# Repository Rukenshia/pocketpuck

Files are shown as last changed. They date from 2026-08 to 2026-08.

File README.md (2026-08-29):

# PocketPuck

> [!NOTE]
> This project is not associated with Amp. It's just a fun little side project to put Puck on my desk.

| | |
| --- | --- |
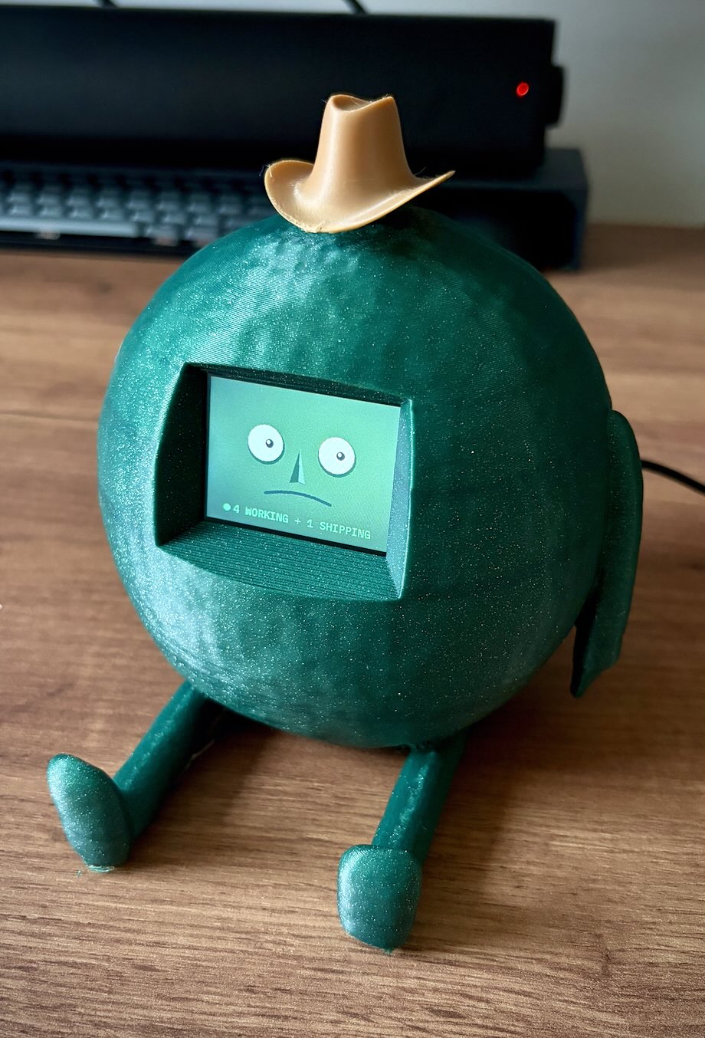
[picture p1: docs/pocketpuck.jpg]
An image of the PocketPuck device
|  | A body for Puck, [Amp](https://ampcode.com)'s companion. Synchronises your current thread state and lets you know if you need to take action. It's also very cute. |

Full video demo:

<video controls src="https://github.com/user-attachments/assets/eebd0190-7875-4f72-867d-91fb097cefb3"></video>

## Usage

Once connected, PocketPuck will automatically synchronise with your current Amp thread state. It will let you know if you have any threads waiting for you or tell you that there are new messages waiting for you (= a thread probably finished).

You press the dial once to open a thread overview that allows you to scroll through your threads. Pressing the dial again will then show a little bit more information on that thread. Long press the dial to get back to the main screen.

To open the Settings, long press the dial from the main screen. You can change the display fae, change whether Puck should blink or not, and reset all settings. Settings are persisted. There are a total of four display faces to choose from: from a very minimal one to reduce distractions to what you can see in the video (and even more unhinged).

## Hardware

- Arduino Nano ESP32 (any ESP32 will work, but you might have to change pinout assignments)
- [Waveshare 2inch LCD Module](https://www.waveshare.com/wiki/2inch_LCD_Module)
  (240 x 320, ST7789V)
- Rotary encoder with push button (KY-040 or similar)

### 3D Models

You can find the 3d models in the `models` directory. You have a choice of multiple hats to give your PocketPuck some extra personality.

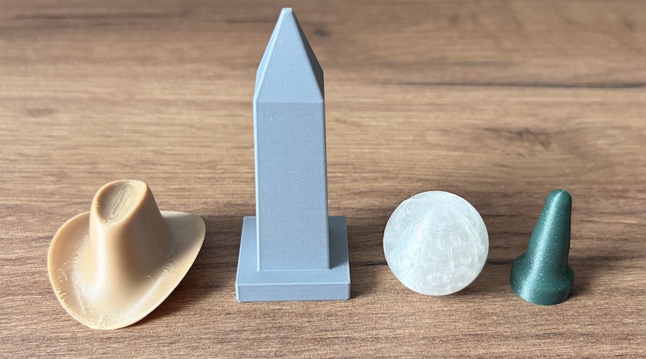
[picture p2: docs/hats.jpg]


| Model Name | Description |
| --- | --- |
| `puck_manual.stl`  | The main body of the PocketPuck. |
| `puck_hat.stl` | A cute cowboy hat. |
| `puck_obelisk.stl` | A small obelisk to put on top of the PocketPuck. |
| `puck_orb.stl` | An orb as a hat. Recommended to print with a translucent filament |
| `puck_knob.stl` | An interestingly shaped knob as a hat. |

You can hot glue the display to the inside of the body or use tape to secure it. The rotary dial goes through the hole and is fastened with a nut.

### Wiring

Disconnect USB power while wiring. The table below refers to the Arduino Nano ESP32 pin labels, not the normal ESP32 GPIO pinout.

| Waveshare LCD | Nano ESP32 | Purpose |
| --- | --- | --- |
| `VCC` | `3V3` | Power |
| `GND` | `GND` | Ground |
| `DIN` | `D11` / `COPI` | SPI data to display |
| `CLK` | `D12` / `CIPO` | Remapped SPI clock |
| `CS` | `D10` | Chip select |
| `DC` | `D7` | Data/command select |
| `RST` | `D8` | Display reset |
| `BL` | `D9` | Backlight, active high |

| Rotary encoder | Nano ESP32 | Purpose |
| --- | --- | --- |
| `CLK` | `D2` | Rotation clock |
| `DT` | `D3` | Rotation direction |
| `SW` | `D4` | Push switch |
| `+` | `D5` | Module pull-up voltage (you should connect this to 3V3 but I was lazy) |
| `GND` | `GND` | Common ground |

### Build and upload

[PlatformIO](https://platformio.org/) is the only required development tool.

```sh
pio run
pio run --target upload
pio device monitor
```

PlatformIO should automatically find the Nano ESP32's USB port. If an upload
cannot find the board, double-press RESET to enter the Arduino bootloader (the
green LED pulses), then run the upload command again.

The display and rotary pin assignments live in
[`include/display_config.h`](include/display_config.h).
The firmware uses the Adafruit GFX and ST7789 libraries, fetched automatically
by PlatformIO.

## Live Amp stats

Amp's API does not support all the thread information that I wanted to display.
PocketPuck therefor uses Rivet endpoint directly to get more detailed information,
meaning this can break at any time since there is no published API contract for this.
The bridge has a fallback to the `amp top` command, which is more stable but less detailed.

The bridge should be deployed on in the same network as PocketPuck. The server
serves traffic over HTTP on port 8765 by default. It is written in [Bun](https://bun.sh/).

I personally run this on a Raspberry Pi, where I also run Amp, meaning that I can use my
existing credentials. You can provide a custom API key using the `AMP_API_KEY` environment variable.

```sh
$HOME/.bun/bin/bun install --frozen-lockfile --production --ignore-scripts
```

Start the bridge service and query it with:

```sh
$HOME/.bun/bin/bun scripts/pocketpuck_bridge.mjs \
  --amp-command "$HOME/.amp/bin/amp"
curl http://localhost:8765/stats
```

By default, the bridge will try to find credentials in

- `$HOME/.config/amp/secrets.json`
- `$XDG_CONFIG_HOME/amp/secrets.json`
- `$HOME/.local/share/amp/secrets.json`

To run the bridge as a systemd user service, use a unit like this (adjust the
repository path if the checkout is not `%h/pocketpuck`):

```ini
[Unit]
Description=PocketPuck Amp bridge
After=network-online.target

[Service]
WorkingDirectory=%h/pocketpuck
ExecStart=%h/.bun/bin/bun scripts/pocketpuck_bridge.mjs --amp-command %h/.amp/bin/amp
# Optional custom-deployment overrides; normal Amp file credentials are discovered.
EnvironmentFile=-%h/.config/pocketpuck/environment
Restart=always

[Install]
WantedBy=default.target
```

## Connecting Your PocketPuck to the Bridge

Copy the example network configuration file to a local file that you can edit:

```sh
cp include/network_config.example.h include/network_config.h
```

Edit the `POCKETPUCK_WIFI_SSID`, `POCKETPUCK_WIFI_PASSWORD`, and `POCKETPUCK_STATS_URL` (for example `http://192.168.178.123:8765/stats`) values accordingly. Note that most ESP32 only support 2.4GHz WiFi networks, so make sure your router is configured correctly.

## FAQ (nobody has asked me anything yet)

> Why?

I sometimes start threads and then go on to do other things (definitely not procrastinating). I wanted a way to know if I have threads waiting for me. So instead of enabling notifications on my phone, I decided to build something completely unnecessary.

> Why is he so thick?

I overestimated how much space I needed inside and I have not modelled anything in Blender for a long time. This was supposed to just take a few days and I wanted to stick to that timeline.
The display being inset so deeply is also a result of me not having enough patience to do things properly in Blender. I've been using OnShape for most of my things recently and am just out of practice.

> Why do his hands look so weird?

It was my first time ever trying to even use the Blender sculpting tools and I regret everything.

> Why PocketPuck? He clearly does not fit into my pocket.

My original idea was much more boring (a small case around the display and a small stand), but I pivoted to something more fun. By that time, the repo already existed.

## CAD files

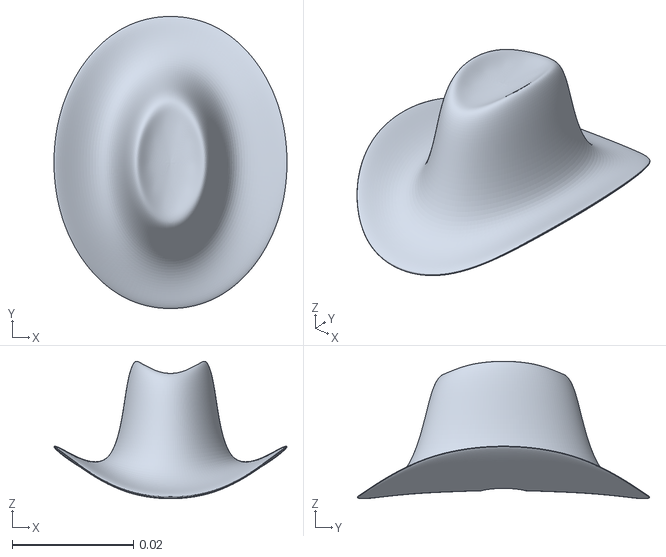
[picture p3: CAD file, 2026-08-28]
models/puck_hat.stl
0.0385 x 0.0483 x 0.0227

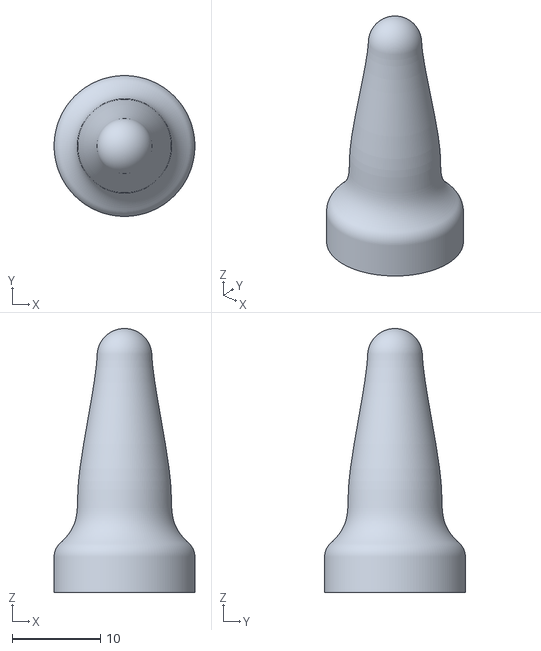
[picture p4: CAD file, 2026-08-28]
models/puck_knob.stl
16.0 x 16.0 x 30.0

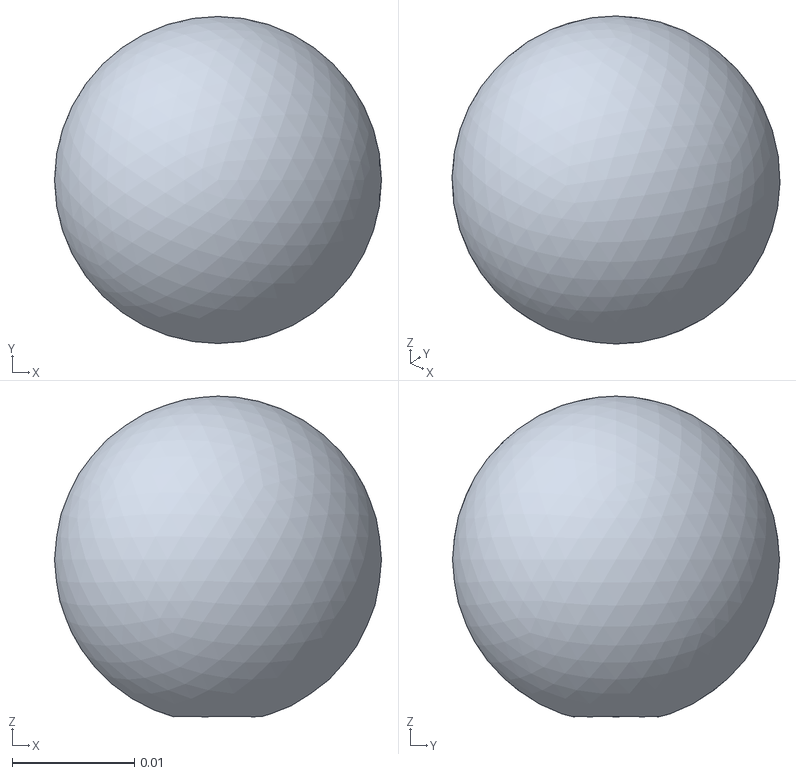
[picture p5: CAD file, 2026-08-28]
models/puck_orb.stl
0.0267 x 0.0267 x 0.0262

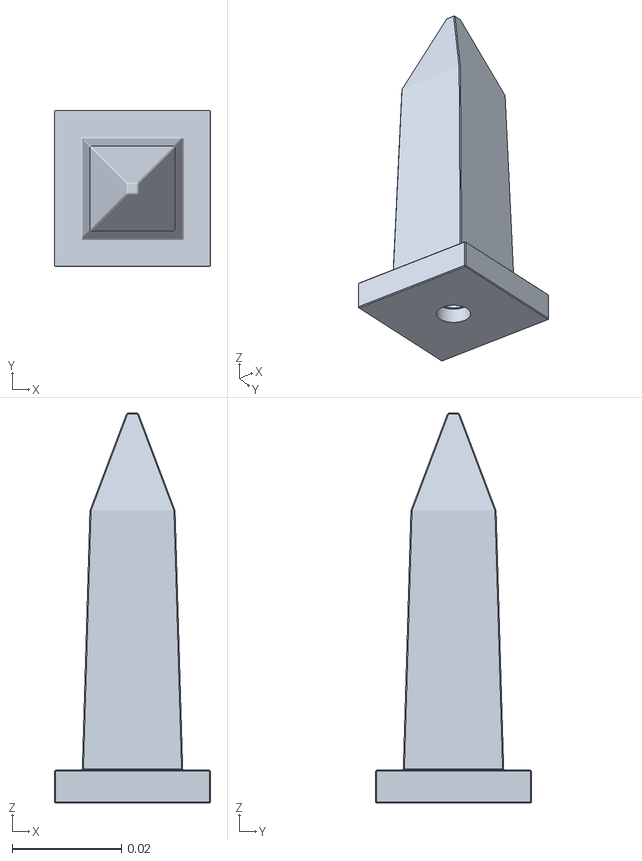
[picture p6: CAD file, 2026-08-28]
models/puck_obelisk.stl
0.0286 x 0.0286 x 0.0713

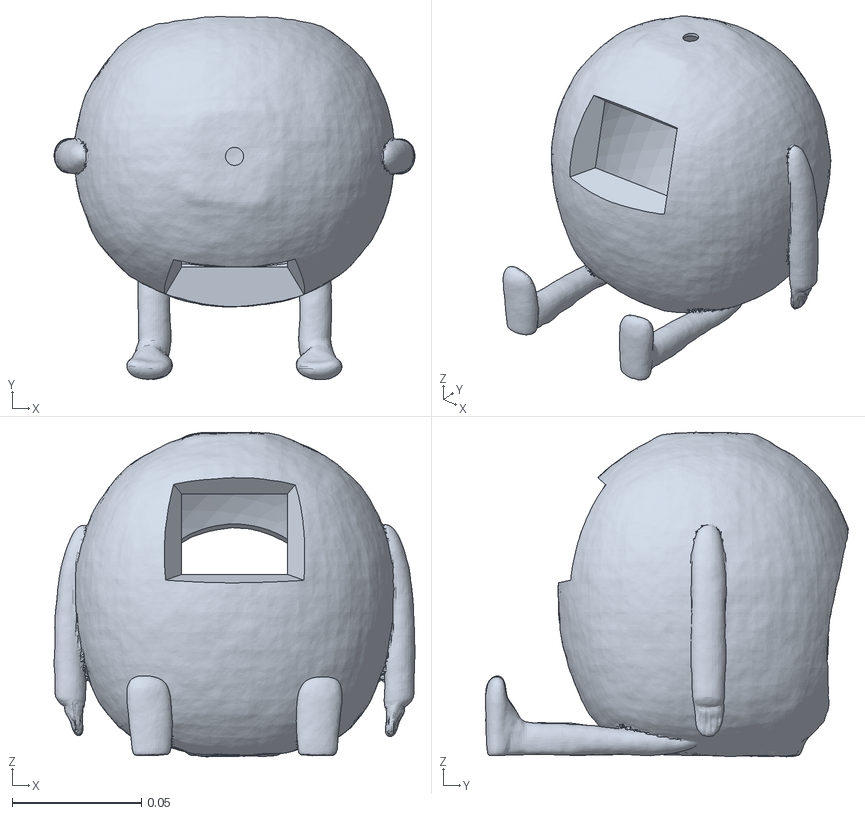
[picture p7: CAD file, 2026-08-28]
models/puck_manual.stl
0.14 x 0.14 x 0.126

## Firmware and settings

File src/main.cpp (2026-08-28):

#include <Adafruit_GFX.h>
#include <Adafruit_ST7789.h>
#include <Arduino.h>
#include <Preferences.h>
#include <SPI.h>
#include <algorithm>
#include <cmath>
#include <cstdio>
#include <cstring>

#include "amp_stats.h"
#include "amp_logo.h"
#include "display_config.h"
#include "fonts/PlexMono9pt7b.h"

// Snapshot-backed UI scenes exceed Arduino's default 8 KB loop task stack.
SET_LOOP_TASK_STACK_SIZE(16 * 1024);

namespace {

Adafruit_ST7789 display(LCD_CS, LCD_DC, LCD_RST);

constexpr int16_t SCREEN_WIDTH = 320;
constexpr int16_t SCREEN_HEIGHT = 240;
constexpr size_t SCREEN_PIXEL_COUNT = SCREEN_WIDTH * SCREEN_HEIGHT;
constexpr uint32_t FRAME_INTERVAL_MS = 80;
constexpr float IRIS_SMOOTHING_TIME_MS = 180.0F;
constexpr uint8_t DEPTH_LAYER_COUNT = 8;
constexpr float FULL_ROTATION_RADIANS = 6.283185307F;
constexpr int16_t FACE_Y_OFFSET = 12;
constexpr uint8_t BACKLIGHT_MIN = 31;
constexpr uint8_t BACKLIGHT_STEP = 32;
constexpr uint32_t BUTTON_DEBOUNCE_MS = 30;
constexpr uint32_t ENCODER_FEEDBACK_MS = 1500;
constexpr uint32_t LONG_PRESS_MS = 700;
constexpr uint32_t MENU_TIMEOUT_MS = 30000;
constexpr uint32_t NOTIFICATION_DURATION_MS = 4200;
constexpr uint32_t SHIPPED_NOTIFICATION_DURATION_MS =
    NOTIFICATION_DURATION_MS + 5000;
constexpr uint8_t NOTIFICATION_QUEUE_LIMIT = 8;
constexpr uint8_t SEEN_EVENT_LIMIT = AMP_THREAD_EVENT_LIMIT;

constexpr uint32_t LOGO_ROTATION_MS = 5000;
constexpr uint32_t STARTUP_LOGO_DURATION_MS = 5000;
constexpr uint32_t CONNECTING_FACE_MIN_DURATION_MS = 2000;
constexpr uint32_t WAKING_ANIMATION_DURATION_MS = 2000;

// Confirmed faces render live Amp state. The picker runs the synchronized
// fixture lifecycle while the dial previews each design.
constexpr uint8_t REEL_VERSION = 6;
constexpr uint8_t REEL_MODE_COUNT = 3;
constexpr uint8_t DEFAULT_REEL_MODE = 1;
constexpr uint8_t DEBUG_FACE_PHASE_COUNT = 5;
constexpr uint32_t REEL_OVERLAY_MS = 1800;
constexpr uint32_t IDLE_MESSAGE_DELAY_MS = 20 * 60 * 1000;
constexpr uint32_t IDLE_MESSAGE_INTERVAL_MS = 20 * 60 * 1000;
constexpr uint32_t IDLE_MESSAGE_DURATION_MS = 2 * 60 * 1000;
const char* const REEL_MODE_NAMES[REEL_MODE_COUNT] = {
    "MINIMAL", "BEACON", "PANIC",
};
const char* const DEBUG_FACE_PHASE_NAMES[DEBUG_FACE_PHASE_COUNT] = {
    "IDLE", "WORKING", "MESSAGE", "ATTENTION", "ALL CLEAR",
};
const char* const IDLE_MESSAGES[] = {
    "Quiet here.",
    "Still here.",
    "Suspiciously quiet.",
    "Nothing has exploded.",
    "I await developments.",
    "A rare moment of order.",
    "Threads asleep. Allegedly.",
    "All systems plausible.",
};

constexpr int16_t LOGO_FRAME_WIDTH = AMP_LOGO_WIDTH;
constexpr int16_t LOGO_FRAME_HEIGHT = AMP_LOGO_HEIGHT + 24;
constexpr int16_t LOGO_FRAME_ROW_BYTES = (LOGO_FRAME_WIDTH + 7) / 8;
constexpr size_t LOGO_FRAME_BYTES =
    LOGO_FRAME_ROW_BYTES * LOGO_FRAME_HEIGHT;

GFXcanvas16 canvas(SCREEN_WIDTH, SCREEN_HEIGHT);
uint8_t logoFrame[LOGO_FRAME_BYTES];
uint8_t logoHighlight[LOGO_FRAME_BYTES];
uint8_t sourceRow[AMP_LOGO_WIDTH];

uint16_t logoBackground;
uint16_t logoDepthColors[4];
uint16_t logoFaceColor;
uint16_t logoHighlightColor;
uint16_t faceShadowColor;
uint16_t eyeShadowColor;
uint16_t eyeColor;
uint16_t pupilColor;
uint16_t eyeHighlightColor;
uint16_t noseShadowColor;
uint16_t noseLightColor;
uint16_t mouthColor;
uint16_t accentColor;
uint16_t unreadColor;
uint16_t textureColor;
uint16_t threadCardColor;
uint16_t workingColor;
uint16_t shippingColor;

uint32_t demoStartedAt = 0;
uint32_t lastFrameAt = 0;
uint32_t initialSetupCompletedAt = 0;
uint32_t wifiConnectionStartedAt = 0;
uint32_t wakingAnimationStartedAt = 0;
bool ampStatsStarted = false;
bool connectingFaceDrawn = false;
uint8_t backlightBrightness = 255;
portMUX_TYPE encoderMux = portMUX_INITIALIZER_UNLOCKED;
DRAM_ATTR const int8_t encoderTransitions[16] = {
    0, -1, 1, 0, 1, 0, 0, -1, -1, 0, 0, 1, 0, 1, -1, 0,
};
volatile uint8_t encoderState = 0;
volatile int8_t encoderQuarterSteps = 0;
volatile int8_t pendingEncoderSteps = 0;
uint32_t lastEncoderStepAt = 0;
bool encoderFeedbackActive = false;
int8_t lastEncoderDirection = 0;
bool buttonReading = false;
bool buttonPressed = false;
bool buttonLongHandled = false;
uint32_t buttonChangedAt = 0;
uint32_t buttonPressedAt = 0;
uint32_t lastBrowserInteractionAt = 0;

enum class UiPage : uint8_t {
  Face,
  MainMenu,
  Settings,
  ThreadList,
  ThreadDetail,
};
enum class NotificationKind : uint8_t {
  None,
  Attention,
  Message,
  ThreadActive,
  Shipped,
};

struct PendingNotification {
  NotificationKind kind = NotificationKind::None;
  char title[AMP_THREAD_TITLE_LENGTH] = "";
  char state[AMP_THREAD_STATE_LENGTH] = "";
};

UiPage uiPage = UiPage::Face;
uint8_t mainMenuIndex = 0;
uint8_t settingsMenuIndex = 0;
bool blinkingEnabled = false;
uint32_t settingsResetAt = 0;
bool debugFaceActive = false;
uint8_t debugFacePhase = 0;
uint32_t debugFacePhaseChangedAt = 0;
uint8_t selectedThreadIndex = 0;
uint8_t firstVisibleThreadIndex = 0;
char selectedThreadId[AMP_THREAD_ID_LENGTH] = "";
char selectedThreadTitle[AMP_THREAD_TITLE_LENGTH] = "";
AmpThreadSummary detailThread;
bool detailUnreadAvailable = false;
uint8_t detailThreadTotal = 0;
NotificationKind notificationKind = NotificationKind::None;
uint32_t notificationElapsedMs = 0;
uint32_t notificationUpdatedAt = 0;
char notificationThreadTitle[AMP_THREAD_TITLE_LENGTH] = "";
char notificationThreadState[AMP_THREAD_STATE_LENGTH] = "";
PendingNotification notificationQueue[NOTIFICATION_QUEUE_LIMIT];
uint8_t notificationQueueCount = 0;
char seenEventIds[SEEN_EVENT_LIMIT][AMP_EVENT_ID_LENGTH] = {};
uint8_t seenEventCount = 0;
uint8_t nextSeenEventIndex = 0;
AmpStatsSnapshot previousStats;
bool statsBaselineReady = false;
uint32_t reelAllClearStartedAt = 0;

uint8_t reelMode = DEFAULT_REEL_MODE;
uint8_t reelModeBeforeSelection = DEFAULT_REEL_MODE;
uint32_t reelModeChangedAt = 0;
bool reelModeSelecting = false;
uint32_t reelSelectionStartedAt = 0;
uint32_t idleMessageCycleStartedAt = 0;

struct FacePose {
  float gazeX = 0.0F;
  float gazeY = 0.0F;
  float leftEyeOpen = 1.0F;
  float rightEyeOpen = 1.0F;
  float eyeScale = 1.0F;
  float pupilScale = 1.0F;
  float mouthCurveY = 150.0F;
  float mouthTilt = 0.0F;
  float xOffset = 0.0F;
  float yOffset = 0.0F;
};

float irisTargetX = 0.0F;
float irisTargetY = 0.0F;
float irisPositionX = 0.0F;
float irisPositionY = 0.0F;
uint32_t irisUpdatedAt = 0;
bool irisSmoothingReady = false;

void pushCanvas();

void IRAM_ATTR handleEncoderChange() {
  const uint8_t newState =
      (digitalRead(ROTARY_CLK) << 1) | digitalRead(ROTARY_DT);

  portENTER_CRITICAL_ISR(&encoderMux);
  encoderQuarterSteps += encoderTransitions[(encoderState << 2) | newState];
  encoderState = newState;
  if (encoderQuarterSteps >= 4) {
    if (pendingEncoderSteps < 100) {
      ++pendingEncoderSteps;
    }
    encoderQuarterSteps = 0;
  } else if (encoderQuarterSteps <= -4) {
    if (pendingEncoderSteps > -100) {
      --pendingEncoderSteps;
    }
    encoderQuarterSteps = 0;
  }
  portEXIT_CRITICAL_ISR(&encoderMux);
}

void adjustBacklight(int8_t direction) {
  const int16_t adjusted = static_cast<int16_t>(backlightBrightness) +
                           direction * BACKLIGHT_STEP;
  backlightBrightness =
      static_cast<uint8_t>(std::max<int16_t>(BACKLIGHT_MIN,
                                             std::min<int16_t>(255, adjusted)));
  analogWrite(LCD_BL, backlightBrightness);
  Serial.printf("Backlight: %u%%\n",
                (backlightBrightness * 100U + 127U) / 255U);
}

void showFace() {
  uiPage = UiPage::Face;
  debugFaceActive = false;
  reelModeSelecting = false;
  encoderFeedbackActive = false;
  Serial.println("Screen: face");
}

void showMainMenu(uint32_t now) {
  if (reelModeSelecting) {
    reelMode = reelModeBeforeSelection;
    reelModeSelecting = false;
  }
  uiPage = UiPage::MainMenu;
  debugFaceActive = false;
  mainMenuIndex = 0;
  lastBrowserInteractionAt = now;
  encoderFeedbackActive = false;
  Serial.println("Screen: main menu");
}

void showSettings(uint32_t now) {
  uiPage = UiPage::Settings;
  debugFaceActive = false;
  settingsMenuIndex = 0;
  lastBrowserInteractionAt = now;
  encoderFeedbackActive = false;
  Serial.println("Screen: settings");
}

void showFacePicker(uint32_t now) {
  uiPage = UiPage::Face;
  debugFaceActive = false;
  reelModeBeforeSelection = reelMode;
  reelModeSelecting = true;
  reelModeChangedAt = now;
  reelSelectionStartedAt = now;
  encoderFeedbackActive = false;
  Serial.println("Face picker: turn to preview, click to confirm");
}

void showDebugFace(uint32_t now) {
  uiPage = UiPage::Face;
  debugFaceActive = true;
  debugFacePhase = 0;
  debugFacePhaseChangedAt = now;
  lastBrowserInteractionAt = now;
  encoderFeedbackActive = false;
  Serial.printf("Debug face: %s; turn to change state, press to return\n",
                DEBUG_FACE_PHASE_NAMES[debugFacePhase]);
}

int16_t selectedThreadPosition(const AmpStatsSnapshot& stats) {
  for (uint8_t index = 0; index < stats.threadCount; ++index) {
    const AmpThreadSummary& thread = stats.threads[index];
    if ((selectedThreadId[0] &&
         std::strcmp(selectedThreadId, thread.id) == 0) ||
        (!selectedThreadId[0] && selectedThreadTitle[0] &&
         std::strcmp(selectedThreadTitle, thread.title) == 0)) {
      return index;
    }
  }
  return -1;
}

void rememberSelectedThread(const AmpThreadSummary& thread) {
  std::snprintf(selectedThreadId, sizeof(selectedThreadId), "%s", thread.id);
  std::snprintf(selectedThreadTitle, sizeof(selectedThreadTitle), "%s",
                thread.title);
}

void keepSelectedThreadVisible(uint8_t threadCount) {
  constexpr uint8_t visibleThreads = 4;
  if (threadCount <= visibleThreads) {
    firstVisibleThreadIndex = 0;
    return;
  }
  if (selectedThreadIndex < firstVisibleThreadIndex) {
    firstVisibleThreadIndex = selectedThreadIndex;
  } else if (selectedThreadIndex >=
             firstVisibleThreadIndex + visibleThreads) {
    firstVisibleThreadIndex = selectedThreadIndex - visibleThreads + 1;
  }
  firstVisibleThreadIndex = std::min<uint8_t>(
      firstVisibleThreadIndex, threadCount - visibleThreads);
}

bool reconcileSelectedThread(const AmpStatsSnapshot& stats) {
  if (!stats.available || stats.threadCount == 0) {
    return false;
  }
  const int16_t position = selectedThreadPosition(stats);
  if (position >= 0) {
    selectedThreadIndex = static_cast<uint8_t>(position);
  } else {
    selectedThreadIndex = std::min<uint8_t>(selectedThreadIndex,
                                            stats.threadCount - 1);
    rememberSelectedThread(stats.threads[selectedThreadIndex]);
  }
  keepSelectedThreadVisible(stats.threadCount);
  return true;
}

void showThreadList(uint32_t now) {
  const AmpStatsSnapshot stats = getAmpStats();
  reconcileSelectedThread(stats);
  uiPage = UiPage::ThreadList;
  lastBrowserInteractionAt = now;
  encoderFeedbackActive = false;
  Serial.println("Screen: thread list");
}

void openSelectedThread(uint32_t now) {
  const AmpStatsSnapshot stats = getAmpStats();
  if (!reconcileSelectedThread(stats)) {
    return;
  }
  detailThread = stats.threads[selectedThreadIndex];
  rememberSelectedThread(detailThread);
  detailUnreadAvailable = stats.unreadAvailable;
  detailThreadTotal = stats.threadCount;
  uiPage = UiPage::ThreadDetail;
  lastBrowserInteractionAt = now;
  Serial.printf("Screen: thread %u of %u\n", selectedThreadIndex + 1,
                stats.threadCount);
}

void navigateThreads(int8_t steps, uint32_t now, bool showDetail) {
  const AmpStatsSnapshot stats = getAmpStats();
  if (!reconcileSelectedThread(stats)) {
    return;
  }
  const int16_t next = static_cast<int16_t>(selectedThreadIndex) + steps;
  selectedThreadIndex = static_cast<uint8_t>(std::max<int16_t>(
      0, std::min<int16_t>(stats.threadCount - 1, next)));
  rememberSelectedThread(stats.threads[selectedThreadIndex]);
  keepSelectedThreadVisible(stats.threadCount);
  lastBrowserInteractionAt = now;
  if (showDetail) {
    detailThread = stats.threads[selectedThreadIndex];
    detailUnreadAvailable = stats.unreadAvailable;
    detailThreadTotal = stats.threadCount;
  }
}

bool refreshThreadDetail() {
  const AmpStatsSnapshot stats = getAmpStats();
  if (!stats.available) {
    return true;
  }
  const int16_t position = selectedThreadPosition(stats);
  if (position < 0) {
    return false;
  }
  selectedThreadIndex = static_cast<uint8_t>(position);
  detailThread = stats.threads[selectedThreadIndex];
  detailUnreadAvailable = stats.unreadAvailable;
  detailThreadTotal = stats.threadCount;
  return true;
}

void saveSelectedFace() {
  Preferences preferences;
  preferences.begin("pocketpuck", false);
  preferences.putUChar("design", reelMode);
  preferences.putUChar("designVer", REEL_VERSION);
  preferences.end();
}

void saveBlinkingPreference() {
  Preferences preferences;
  preferences.begin("pocketpuck", false);
  preferences.putBool("blink", blinkingEnabled);
  preferences.remove("noBlink");
  preferences.end();
}

void resetSettings(uint32_t now) {
  Preferences preferences;
  preferences.begin("pocketpuck", false);
  preferences.clear();
  preferences.end();

  reelMode = DEFAULT_REEL_MODE;
  blinkingEnabled = false;
  debugFaceActive = false;
  debugFacePhase = 0;
  debugFacePhaseChangedAt = now;
  reelModeChangedAt = now;
  settingsResetAt = now;
  Serial.println("Settings reset to defaults");
}

void handleShortPress(uint32_t now) {
  if (uiPage == UiPage::Face && debugFaceActive) {
    showSettings(now);
  } else if (uiPage == UiPage::Face && reelModeSelecting) {
    reelModeSelecting = false;
    reelModeChangedAt = now;
    saveSelectedFace();
    Serial.printf("Design confirmed: %u/%u %s\n", reelMode + 1,
                  REEL_MODE_COUNT, REEL_MODE_NAMES[reelMode]);
  } else if (uiPage == UiPage::MainMenu) {
    if (mainMenuIndex == 0) {
      showFacePicker(now);
    } else {
      showSettings(now);
    }
  } else if (uiPage == UiPage::Settings) {
    lastBrowserInteractionAt = now;
    if (settingsMenuIndex == 0) {
      blinkingEnabled = !blinkingEnabled;
      saveBlinkingPreference();
      Serial.printf("Blinking: %s\n", blinkingEnabled ? "enabled" : "disabled");
    } else if (settingsMenuIndex == 1) {
      showDebugFace(now);
    } else {
      resetSettings(now);
    }
  } else if (uiPage == UiPage::ThreadDetail) {
    showThreadList(now);
  } else if (uiPage == UiPage::ThreadList) {
    openSelectedThread(now);
  } else {
    showThreadList(now);
  }
}

void updateControls(uint32_t now) {
  portENTER_CRITICAL(&encoderMux);
  const int8_t encoderSteps = pendingEncoderSteps;
  pendingEncoderSteps = 0;
  portEXIT_CRITICAL(&encoderMux);
  if (encoderSteps != 0) {
    if (uiPage == UiPage::MainMenu) {
      const int16_t next = static_cast<int16_t>(mainMenuIndex) + encoderSteps;
      mainMenuIndex = static_cast<uint8_t>(
          std::max<int16_t>(0, std::min<int16_t>(1, next)));
      lastBrowserInteractionAt = now;
    } else if (uiPage == UiPage::Settings) {
      const int16_t next =
          static_cast<int16_t>(settingsMenuIndex) + encoderSteps;
      settingsMenuIndex = static_cast<uint8_t>(
          std::max<int16_t>(0, std::min<int16_t>(2, next)));
      lastBrowserInteractionAt = now;
    } else if (uiPage == UiPage::ThreadList) {
      navigateThreads(encoderSteps, now, false);
    } else if (uiPage == UiPage::ThreadDetail) {
      navigateThreads(encoderSteps, now, true);
    } else if (reelModeSelecting) {
      const int16_t next =
          (static_cast<int16_t>(reelMode) + encoderSteps) % REEL_MODE_COUNT;
      reelMode = static_cast<uint8_t>((next + REEL_MODE_COUNT) %
                                      REEL_MODE_COUNT);
      reelModeChangedAt = now;
      Serial.printf("Design preview: %u/%u %s\n", reelMode + 1,
                    REEL_MODE_COUNT, REEL_MODE_NAMES[reelMode]);
    } else if (debugFaceActive) {
      const int16_t next =
          (static_cast<int16_t>(debugFacePhase) + encoderSteps) %
          DEBUG_FACE_PHASE_COUNT;
      debugFacePhase = static_cast<uint8_t>(
          (next + DEBUG_FACE_PHASE_COUNT) % DEBUG_FACE_PHASE_COUNT);
      debugFacePhaseChangedAt = now;
      Serial.printf("Debug face: %s\n",
                    DEBUG_FACE_PHASE_NAMES[debugFacePhase]);
    } else {
      lastEncoderDirection = encoderSteps > 0 ? 1 : -1;
      for (int8_t step = 0; step < std::abs(encoderSteps); ++step) {
        adjustBacklight(lastEncoderDirection);
      }
      lastEncoderStepAt = now;
      encoderFeedbackActive = true;
    }
  }

  const bool reading = digitalRead(ROTARY_SW) == LOW;
  if (reading != buttonReading) {
    buttonReading = reading;
    buttonChangedAt = now;
  }
  if (now - buttonChangedAt >= BUTTON_DEBOUNCE_MS &&
      buttonPressed != buttonReading) {
    buttonPressed = buttonReading;
    if (buttonPressed) {
      buttonPressedAt = now;
      buttonLongHandled = false;
    } else if (!buttonLongHandled) {
      handleShortPress(now);
    }
  }
  if (buttonPressed && !buttonLongHandled &&
      now - buttonPressedAt >= LONG_PRESS_MS) {
    buttonLongHandled = true;
    if (uiPage != UiPage::Face) {
      showFace();
    } else {
      showMainMenu(now);
    }
  }
  if ((uiPage == UiPage::MainMenu || uiPage == UiPage::Settings) &&
      now - lastBrowserInteractionAt >= MENU_TIMEOUT_MS) {
    showFace();
  }
}

float clamp01(float value) {
  if (value < 0.0F) {
    return 0.0F;
  }
  if (value > 1.0F) {
    return 1.0F;
  }
  return value;
}

float smoothStep(float value) {
  const float clamped = clamp01(value);
  return clamped * clamped * (3.0F - 2.0F * clamped);
}

float mix(float from, float to, float amount) {
  return from + (to - from) * amount;
}

float blinkAt(uint32_t elapsed, uint32_t center, uint32_t duration = 240) {
  if (!blinkingEnabled) {
    return 1.0F;
  }
  const int32_t distance =
      std::abs(static_cast<int32_t>(elapsed) - static_cast<int32_t>(center));
  const float halfDuration = duration / 2.0F;
  if (distance >= halfDuration) {
    return 1.0F;
  }
  return smoothStep(distance / halfDuration);
}

void setBitmapPixel(uint8_t* bitmap, int16_t x, int16_t y) {
  bitmap[y * LOGO_FRAME_ROW_BYTES + x / 8] |= 0x80 >> (x % 8);
}

void loadSourceRow(int16_t y) {
  std::memset(sourceRow, 0, sizeof(sourceRow));

  uint16_t offset = pgm_read_word(&AMP_LOGO_ROW_OFFSETS[y]);
  const uint8_t spanCount = pgm_read_byte(&AMP_LOGO_ROW_SPANS[offset++]);
  for (uint8_t span = 0; span < spanCount; ++span) {
    const uint8_t start = pgm_read_byte(&AMP_LOGO_ROW_SPANS[offset++]);
    const uint8_t end = pgm_read_byte(&AMP_LOGO_ROW_SPANS[offset++]);
    std::memset(sourceRow + start, 1, end - start + 1);
  }
}
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
void loop() {
  const uint32_t now = millis();
  updateControls(now);
  if (!ampStatsStarted && now - demoStartedAt >= STARTUP_LOGO_DURATION_MS) {
    beginAmpStats();
    ampStatsStarted = true;
    wifiConnectionStartedAt = now;
  }
  if (now - lastFrameAt < FRAME_INTERVAL_MS) {
    return;
  }

  lastFrameAt = now;
  updateNotifications(now);
  if (!ampStatsStarted) {
    drawLogo(now - demoStartedAt);
    pushCanvas();
    return;
  }
  if (initialSetupCompletedAt == 0) {
    const AmpStatsSnapshot stats = getAmpStats();
    const uint32_t connectingElapsed = now - wifiConnectionStartedAt;
    if ((!stats.configured ||
         (!stats.wifiConnected && stats.initialAttemptComplete)) &&
        connectingElapsed >= CONNECTING_FACE_MIN_DURATION_MS) {
      initialSetupCompletedAt = now;
    } else {
      if (wakingAnimationStartedAt == 0 && stats.wifiConnected &&
          connectingElapsed >= CONNECTING_FACE_MIN_DURATION_MS) {
        wakingAnimationStartedAt = now;
      }
      if (wakingAnimationStartedAt == 0) {
        if (!connectingFaceDrawn) {
          AmpStatsSnapshot connectingStats = stats;
          connectingStats.configured = true;
          connectingStats.wifiConnected = false;
          FacePose sleepingPose = neutralPose();
          sleepingPose.leftEyeOpen = 0.0F;
          sleepingPose.rightEyeOpen = 0.0F;
          drawFace(sleepingPose);
          drawStatsPanel(connectingStats);
          pushCanvas();
          connectingFaceDrawn = true;
        }
        return;
      }

      const uint32_t wakingElapsed = now - wakingAnimationStartedAt;
      if (wakingElapsed < WAKING_ANIMATION_DURATION_MS) {
        drawFace(wakingPose(wakingElapsed));
        pushCanvas();
        return;
      }
      initialSetupCompletedAt = now;
    }
  }

  const uint32_t mainElapsed = now - initialSetupCompletedAt;
  if (uiPage == UiPage::MainMenu) {
    drawMainMenu();
    pushCanvas();
  } else if (uiPage == UiPage::Settings) {
    drawSettings(now);
    pushCanvas();
  } else if (uiPage == UiPage::ThreadDetail) {
    if (refreshThreadDetail()) {
      drawThreadDetail();
      pushCanvas();
    } else {
      showThreadList(now);
      drawThreadOverview();
      pushCanvas();
    }
  } else if (uiPage == UiPage::ThreadList) {
    drawThreadOverview();
    pushCanvas();
  } else {
    drawDesignReelFrame(mainElapsed, now);
  }
}

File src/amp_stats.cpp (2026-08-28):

#include "amp_stats.h"

#include <ArduinoJson.h>
#include <HTTPClient.h>
#include <WiFi.h>
#include <cstring>
#include <freertos/FreeRTOS.h>
#include <freertos/semphr.h>
#include <freertos/task.h>

#if __has_include("network_config.h")
#include "network_config.h"
#else
#define POCKETPUCK_WIFI_SSID ""
#define POCKETPUCK_WIFI_PASSWORD ""
#define POCKETPUCK_STATS_URL ""
#endif

namespace {

constexpr uint32_t WIFI_RETRY_INTERVAL_MS = 15000;
constexpr uint32_t STATS_POLL_INTERVAL_MS = 10000;
constexpr uint32_t INITIAL_ATTEMPT_TIMEOUT_MS = 20000;
constexpr uint16_t HTTP_TIMEOUT_MS = 3000;
constexpr uint32_t STATS_TASK_STACK_BYTES = 8192;

AmpStatsSnapshot publishedStats;
AmpStatsSnapshot workerStats;
SemaphoreHandle_t statsMutex = nullptr;
uint32_t statsStartedAt = 0;
uint32_t lastWifiAttemptAt = 0;
uint32_t lastStatsPollAt = 0;

bool hasConfiguration() {
  return POCKETPUCK_WIFI_SSID[0] != '\0' && POCKETPUCK_STATS_URL[0] != '\0';
}

template <size_t Size>
void copyJsonString(char (&output)[Size], JsonVariantConst value,
                    const char* fallback = "") {
  std::strncpy(output, value | fallback, Size - 1);
  output[Size - 1] = '\0';
}

void publishStats() {
  if (!statsMutex) {
    publishedStats = workerStats;
    return;
  }
  if (xSemaphoreTake(statsMutex, portMAX_DELAY) == pdTRUE) {
    publishedStats = workerStats;
    xSemaphoreGive(statsMutex);
  }
}

void connectWifi(uint32_t now) {
  lastWifiAttemptAt = now;
  Serial.printf("Connecting to WiFi %s\n", POCKETPUCK_WIFI_SSID);
  WiFi.disconnect();
  WiFi.begin(POCKETPUCK_WIFI_SSID, POCKETPUCK_WIFI_PASSWORD);
}

void fetchStats() {
  HTTPClient http;
  http.setConnectTimeout(HTTP_TIMEOUT_MS);
  http.setTimeout(HTTP_TIMEOUT_MS);
  if (!http.begin(POCKETPUCK_STATS_URL)) {
    Serial.println("Unable to initialize the stats request");
    workerStats.available = false;
    workerStats.reconnecting = false;
    return;
  }

  const int statusCode = http.GET();
  if (statusCode != HTTP_CODE_OK) {
    Serial.printf("Stats request failed: HTTP %d\n", statusCode);
    workerStats.available = false;
    workerStats.reconnecting = false;
    http.end();
    return;
  }

  JsonDocument response;
  const DeserializationError error = deserializeJson(response, http.getStream());
  http.end();
  if (error || !response["working"].is<uint16_t>() ||
      !response["needsAttention"].is<uint16_t>() ||
      !response["idle"].is<uint16_t>()) {
    Serial.printf("Invalid stats response: %s\n",
                  error ? error.c_str() : "missing required counts");
    workerStats.available = false;
    workerStats.reconnecting = false;
    return;
  }

  if (response["reconnecting"] | false) {
    Serial.println("Amp bridge is reconnecting");
    workerStats.available = false;
    workerStats.reconnecting = true;
    return;
  }

  workerStats.attentionAvailable =
      response["capabilities"]["detailedStates"] | false;
  if (workerStats.attentionAvailable) {
    workerStats.working = response["headline"]["working"] | 0;
    workerStats.needsAttention = response["headline"]["needsAttention"] | 0;
    workerStats.idle = response["headline"]["idle"] | 0;
  } else {
    workerStats.working = response["running"].as<uint16_t>();
    workerStats.needsAttention = 0;
    workerStats.idle = response["idle"].as<uint16_t>();
  }
  workerStats.unreadAvailable = response["capabilities"]["unread"] | false;
  workerStats.unread =
      workerStats.unreadAvailable ? response["unread"] | 0 : 0;
  const bool shippingAvailable =
      response["capabilities"]["shipping"] | false;
  workerStats.shipping = shippingAvailable ? response["shipping"] | 0 : 0;
  workerStats.shippedAvailable = response["capabilities"]["shipped"] | false;
  workerStats.shipped =
      workerStats.shippedAvailable ? response["shipped"] | 0 : 0;
  workerStats.eventsAvailable = response["capabilities"]["events"] | false;
  workerStats.total = response["total"] | static_cast<uint16_t>(
                                            workerStats.working +
                                            workerStats.needsAttention +
                                            workerStats.idle);

  workerStats.threadCount = 0;
  for (JsonObjectConst thread : response["items"].as<JsonArrayConst>()) {
    if (workerStats.threadCount >= AMP_THREAD_SUMMARY_LIMIT) {
      break;
    }
    AmpThreadSummary& summary =
        workerStats.threads[workerStats.threadCount++];
    copyJsonString(summary.id, thread["id"]);
    copyJsonString(summary.title, thread["title"], "Untitled thread");
    copyJsonString(summary.project, thread["project"]);
    copyJsonString(summary.state, thread["state"], "idle");
    summary.unread = thread["unread"] | false;
    summary.shipping = thread["shipping"] | false;
    summary.shipped = thread["shipped"] | false;
    summary.projectResolved = thread["projectResolved"] | false;
  }

  workerStats.eventCount = 0;
  if (workerStats.eventsAvailable) {
    for (JsonObjectConst event : response["events"].as<JsonArrayConst>()) {
      if (workerStats.eventCount >= AMP_THREAD_EVENT_LIMIT) {
        break;
      }
      AmpThreadEvent& summary = workerStats.events[workerStats.eventCount++];
      copyJsonString(summary.id, event["id"]);
      copyJsonString(summary.title, event["title"], "Amp thread");
      copyJsonString(summary.state, event["state"]);
      copyJsonString(summary.kind, event["kind"]);
    }
  }

  workerStats.reconnecting = false;
  workerStats.available = true;
  workerStats.initialAttemptComplete = true;
  Serial.printf(
      "Amp threads: %u working, %u shipping, %u need attention, %u unread, %u idle\n",
      workerStats.working, workerStats.shipping, workerStats.needsAttention,
      workerStats.unread, workerStats.idle);
}
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

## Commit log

2026-08-26 Add PocketPuck display demo
    Amp-Thread-ID: https://ampcode.com/threads/T-01a03fa3-654d-73c9-9ab3-82b89909c155
2026-08-26 Add live Amp thread stats over WiFi
    Amp-Thread-ID: https://ampcode.com/threads/T-01a03fe0-d9a8-7769-8144-d15340eed838
2026-08-26 Redesign PocketPuck live thread UI
    Amp-Thread-ID: https://ampcode.com/threads/T-01a03ffc-d100-71ae-86ba-62632d1545da
    [amp_stats.cpp, amp_stats.h, main.cpp]
2026-08-26 Add production Amp discovery and remap display clock
    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
2026-08-26 Refine PocketPuck thread attention UI
    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
2026-08-27 Add rotary thread browser and bridge resync
    Amp-Thread-ID: https://ampcode.com/threads/T-01a04261-dae5-72b2-8c8b-2f48032a4d0d
2026-08-27 Show thread browser only on demand
    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
2026-08-27 Add live PocketPuck notification designs
    Amp-Thread-ID: https://ampcode.com/threads/T-01a0429d-d42a-758d-8139-29fa913e84d9
2026-08-27 Add settings menu and Ship notifications
    Amp-Thread-ID: https://ampcode.com/threads/T-01a043d4-2a22-7300-8d3e-085e70fccd46
2026-08-27 Add font selection and combined shipping status
    Amp-Thread-ID: https://ampcode.com/threads/T-01a044a6-0c4c-72c4-9098-c7b86f17dafd
2026-08-27 Put status counts before labels
    Amp-Thread-ID: https://ampcode.com/threads/T-01a044b3-fb89-7551-b898-f96a17f1a574
2026-08-28 Add face debugging and apply selected fonts
    Amp-Thread-ID: https://ampcode.com/threads/T-01a044a6-9f58-76c9-8d3d-ee300b04b85a
2026-08-28 Improve face state transitions and bridge feedback
    Amp-Thread-ID: https://ampcode.com/threads/T-01a04766-f0a7-75ae-af44-8bf3d76d17fa
2026-08-28 Finalize PocketPuck face designs
    Amp-Thread-ID: https://ampcode.com/threads/T-01a04782-ebcc-77d5-9cdf-9ffa2d646c31
2026-08-28 Refine Puck face behavior and interface
    Amp-Thread-ID: https://ampcode.com/threads/T-01a047bf-3d48-71c7-badd-56651a6ac8c4
2026-08-28 Prevent shipped threads from appearing active
    Amp-Thread-ID: https://ampcode.com/threads/T-01a047c9-518d-721d-bab8-03b0e62fd6a3
2026-08-28 Prepare PocketPuck for public release
    Amp-Thread-ID: https://ampcode.com/threads/T-01a047dc-2698-7328-8857-5d17cc78cf36
2026-08-28 Improve PocketPuck thread status experience
    Amp-Thread-ID: https://ampcode.com/threads/T-01a048c1-3caa-735e-b789-59cc0730ecdb
2026-08-28 feat: add models
    [puck_hat.stl, puck_knob.stl, puck_manual.stl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]
